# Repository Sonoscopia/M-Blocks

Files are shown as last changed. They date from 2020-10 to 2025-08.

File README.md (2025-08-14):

# M-Blocks
Modular MIDI Controllers

## INFO
M-Blocks is a projected developed by Sonoscopia Associação Cultural (www.sonoscopia.pt). 
It consists of several MIDI controllers (M-Controllers) that can be patched to a receiving interface (M-Brain) in a modular fashion, that is, connecting an arbitrary number (32 max.) and type of controllers such as buttons, knobs, faders, encoders, etc. 
The M-Brain than receives data from all the controllers via and maps them to MIDI messages sent to the output, either through USB (future implementation) or MIDI DIN connections.
The communication between modules is made using I2C (Inter-Integrated Circuit) using the Arduino platform (www.arduino.cc).  

### Note to programmers
When programming an M-Brain for the first time do not forget to set the EEPROM memory using /utilities/EEPROM_Preset_Clear/

## CHANGELOG

### version 0.1.2 (phobosfeijoada)
Fully functional M-Brain prototype and M-Controllers.
Continuous controls (ex: knobs) can now output notes, [see commit](https://github.com/Sonoscopia/M-Blocks/commit/bef133f0ddcc1b52bf48fc73a7da5345fef3f352).
M-Toggle code was modified to (MToggleAsButton) acting as M-Button to work with Phobos.
There are still some bugs when programming M-Brain but it works as long as one follows the manual and pays attention to the LED's.

### version 0.1.1 (francesinha)
Fully functional M-Brain prototype and M-Controllers. Needs testing...

### version 0.1.0 (protobrain)
First working version for M-Brain protoype version (the version with LED's instead of a screen). 

### version 0.0.3 (gopro)
As the code for M-Brain is getting bigger I moved the code development to Atmel Studio. In the 'firmware' folder should be a version to compile in Arduino IDE for those of you who don't have Atmel Studio. 

### version 0.0.2 (whoisthemaster)
Inverted Master/Slave relationship. 
Now M-Brain is the slave and M-Controllers are masters.
This way the controllers send data whenever their hardware sensor data changes, while the slave (M-Brain) is requested to read this data. 

### version 0.0.1 (first prototype)
First working sketch containing two modules (MBrain and MToggle).
In this version the controller (MToggle) acts as a Slave device and MBrain acts as a Master device, where the slave is constantly sending data to the master with a flag to let the master know if data has changed or not. 

## CONTRIBUTORS 
Contributors: Gustavo Costa, Tiago Ângelo, Rui Dias, Ján Solčáni and PierrePierrePierre.

## DEPENDENCIES & ACKNOWLEDGEMENTS
- Wire library (https://www.arduino.cc/en/reference/wire) 
- EEPROM library (https://www.arduino.cc/en/Reference/EEPROM)
- Rotary library by Ben Buxton(https://github.com/brianlow/Rotary)
- MIDI Library by François Best (https://github.com/FortySevenEffects/arduino_midi_library)
- TimerOne Library (https://www.arduino.cc/reference/en/libraries/timerone/)

## LICENSE
[][cc-by-nc]

This work is licensed under a
[Creative Commons Attribution-NonCommercial 4.0 International License][cc-by-nc].

[][cc-by-nc]

[cc-by-nc]: https://creativecommons.org/licenses/by-nc/4.0/
[cc-by-nc-image]: https://licensebuttons.net/l/by-nc/4.0/88x31.png
[cc-by-nc-shield]: https://img.shields.io/badge/License-CC%20BY--NC%204.0-lightgrey.svg

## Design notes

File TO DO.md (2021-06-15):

# TO DO 

- change all M-Encoders debug baud rate to 9600 (it's just more common!...)

- hardware fix on M-Brain: protect TRRS sockets from delivering 12V to the I2C SCL and SDA connections when connecting cables after the unit is already powered (can this be done only in the M-Brain instead of adding circuitry to all M-Controllers ???)

- make code for: M-Encoders and M-Trackpad

- M-Brain: check resetMsg() - does it need to be called so often ??? 

- M-Brain: resetMsg() function name is misleading!! Change name

- M-Brain: line:272 - does setting the global channel needs to have an I2C message received ?!?!?!

- make M-Brain code a bit more efficient (leave original code commented to facilitate understanding)

- implement USB MIDI 

- buy/apply rubber feet to the cases

- buy/apply velcro dust protection on the M-Fader faders

# NOTES

- the M-Encoder board (eagle file) is a bit messy: clean it up!

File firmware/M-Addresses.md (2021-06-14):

#M-Controllers Address List: 

(Address from 0 to 31. Not to be confused with I2C address!)

0: M-Toggle1
1: M-Knob1
2: M-Button1
3: M-Fader1
4: M-Joystick1
5: M-Enc-C1 (control change)
6: M-Enc-C1 (notes)
7: M-Enc-D1 (control change) 
8: M-Enc-D1 (notes)

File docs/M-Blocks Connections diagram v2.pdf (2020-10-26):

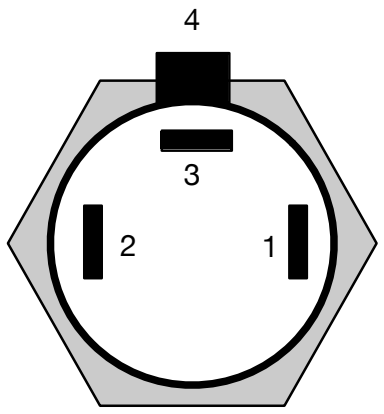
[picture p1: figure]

+12V
SCL
SDA
GND
1) +12V
2) SCL
3) SDA
4) GND

BROWN
RED
ORANGE

YELLOW SDA SCL

GND
+12V

## TRRS CONNECTIONS

(latest version 26-10-2020)

## MOLEX CONNECTIONS

SDA
SCL
GND
+12V
1) SDA
2) SCL
3) GND
4) +12V

BROWN
RED
ORANGE

YELLOW SDA SCL

GND
+12V

## TRRS CONNECTIONS

(older version)

## MOLEX CONNECTIONS

## WARNING

!

Having the +12V connected to the TRRS Sleeve prevents short-circuits when connecting modules while the M-BRAIN is already powered !!!

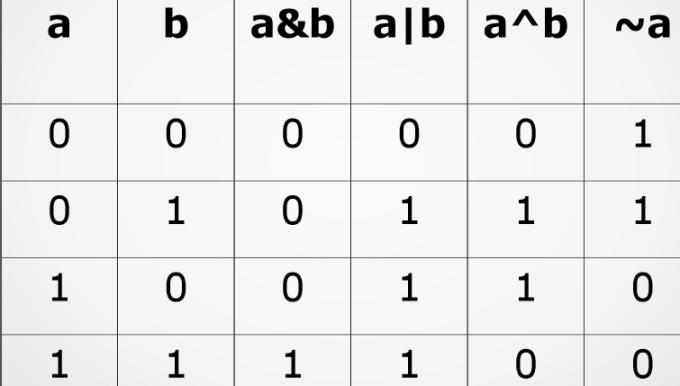
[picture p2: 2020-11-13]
docs/bitwise operator table.png

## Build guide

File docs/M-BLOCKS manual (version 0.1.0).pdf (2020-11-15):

# M-BLOCKS

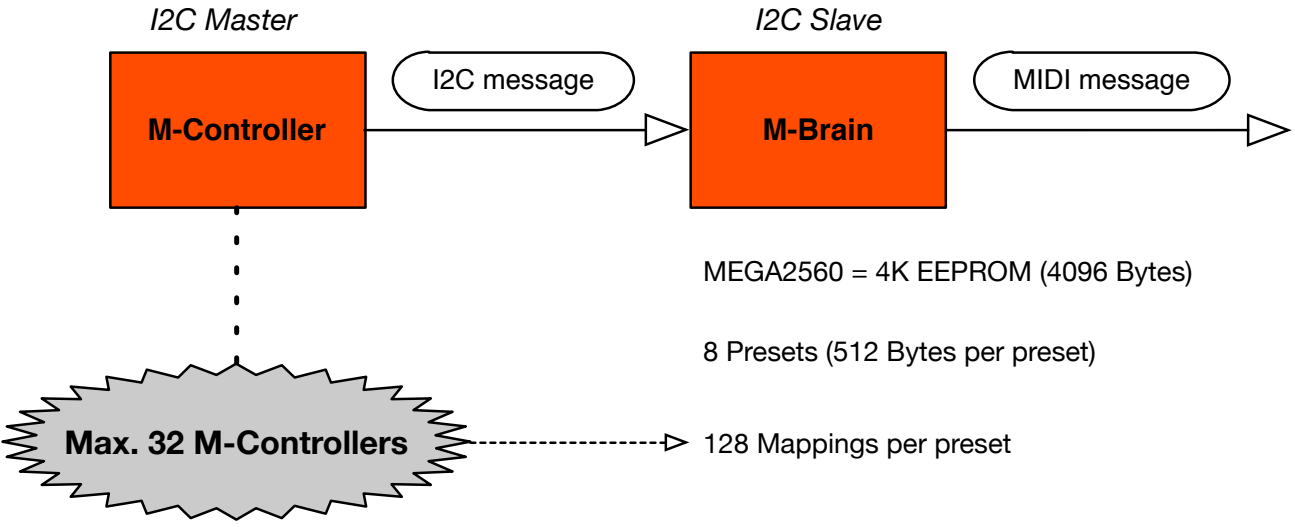
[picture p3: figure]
M-Controller; M-Brain; I2C Master; I2C Slave; I2C message; MIDI message; Max. 32 M-Controllers; MEGA2560 = 4K EEPROM (4096 Bytes); 8 Presets (512 Bytes per preset); 128 Mappings per preset

M-Encoders count as 2 M-Controllers. Encoder rotation as 1 controller and encoder button as another controller. By default encoder button press speeds up encoder rotation. Hold encoder button at startup to enable button output as separate message.

### NOTE:

## I2C Message

CTRL
ID

CTRL
Data

2 Bytes

7-bit (0 to 127)
ex: knob position

7-bit:

M-Controller ID (0 to 31)

Control ID (0 to 3)

unused
8th bit

0 0 0 0 0 0 0 0

Messages are sent upon control data change.

### Example

1 2

3 4

M-Knob

M-Controller ID = 4

M-Controller ID = 4

Control ID = 2

0 1 0 0 0 1 0 0

## EEPROM Memory

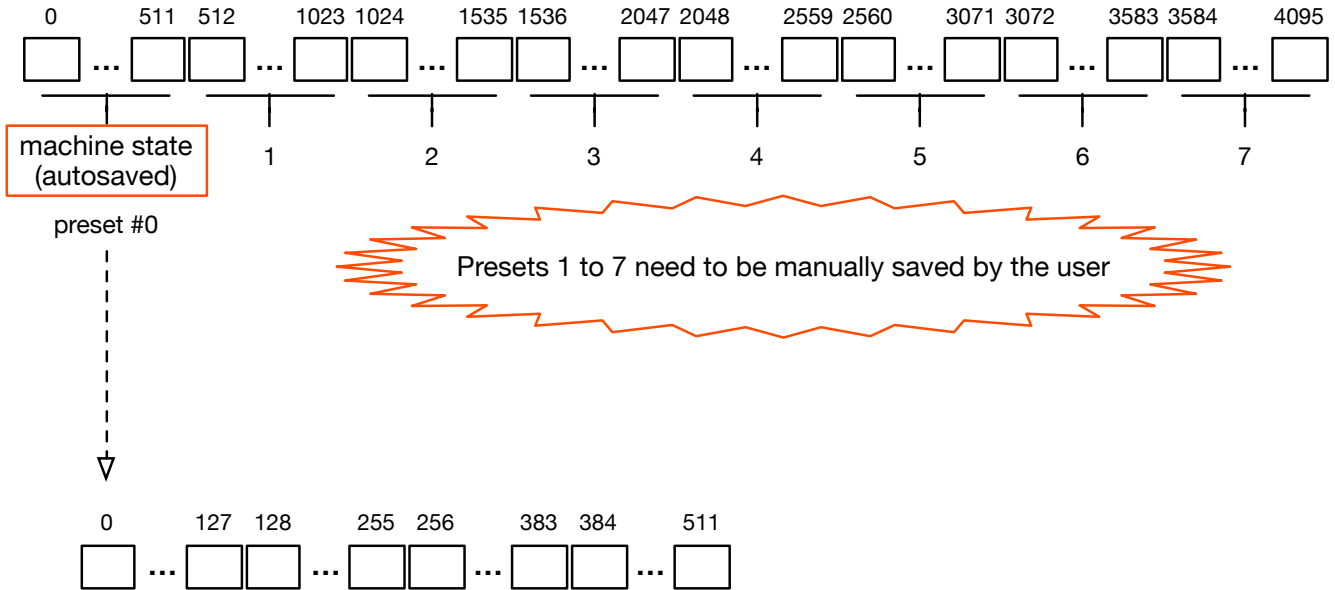
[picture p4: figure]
preset #0; machine state; (autosaved)

Presets 1 to 7 need to be manually saved by the user

CH | NOTE | VEL | CC
MIDI Channel | MIDI Note | Max. Velocity | CC number

NOTE: CTRL ID maps directly to EEPROM memory index

### Example

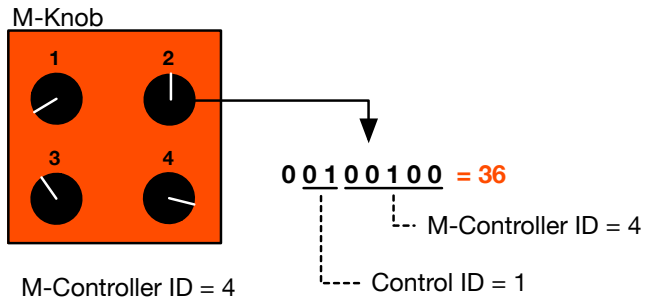
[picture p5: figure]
M-Knob; M-Controller ID = 4; Control ID = 1

CH = EEPROM [ 0 + 36 ]
NOTE = EEPROM [ 128 + 36 ] VEL = EEPROM [ 256 + 36 ]
CC = EEPROM [ 384 + 36 ]

# USER MANUAL

1) Set NOTE mapping
1.1) Press and hold [NOTE] + [Controller] => (LED - blink 250ms)
1.2) Press [LOAD] to EXIT => (LED - stop blinking)
1.3.1) Rotate [ENCODER] to set note number => (LED - display note number)
1.3.2) Press [ENTER] to confirm => (LED - stop blinking)

[NAME] = M-Brain button name
[Controller] = activate M-Controller hardware input (ex: knob, button, etc.) => (LED - xxxxxx) = represent 7-led activity
=> (LEDX - xxxxxx) = represent X-led activity
=> (LED13 - xxxx) = represent built_in led activity
2) Set MAXIMUM VELOCITY mapping
2.1) Press and hold [NOTE + CC] + [Controller] => (LED - blink 125ms)
2.2) Press [LOAD] to EXIT => (LED - stop blinking)
2.3.1) Rotate [ENCODER] to set maximum velocity => (LED - display velocity number)
2.3.2) Press [ENTER] to confirm => (LED - stop blinking)
3) Set CC mapping
3.1) Press and hold [CC] + [Controller] => (LED - blink 250ms)
3.2) Press [LOAD] to EXIT => (LED - stop blinking)
3.3.1) Rotate [ENCODER] to set CC number => (LED - display CC number)
3.3.2) Press [ENTER] to confirm => (LED - stop blinking)

6) SAVE preset
6.1) Press [SAVE] => (LED - blink 500ms)
6.2) Press [SAVE] again to EXIT => (LED - stop blinking)
6.3.1) Rotate [ENCODER] to set preset location => (LED - display slot number)
6.3.2) Press [ENTER] to save => (LED - blink twice)
7) LOAD preset
7.1) Press [LOAD] => (LED - blink 1000ms)
7.2) Press [LOAD] again to EXIT => (LED - stop blinking)
7.3.1) Rotate [ENCODER] to set preset location => (LED - display slot number)
7.3.2) Press [ENTER] to load => (LED - blink twice)
4) Set CH mapping (channel 0 = GLOBAL CH)
4.1) Press and hold [NOTE + LOAD] + [Controller] => (LED - blink 125ms)
4.2) Press [LOAD] to EXIT => (LED - stop blinking)
4.3.1) Rotate [ENCODER] to set CH number => (LED - display CC number)
4.3.2) Press [ENTER] to confirm => (LED - stop blinking)
5) Set GLOBAL CH
5.1) Press and hold [NOTE + CC + LOAD] + [Controller] => (LED - blink 250ms)
5.2) Press [LOAD] to EXIT => (LED - stop blinking)
5.3.1) Rotate [ENCODER] to set CH number => (LED - display CC number)
5.3.2) Press [ENTER] to confirm => (LED - stop blinking)
8) Clear preset 0 / init blank state
8.1) Disconnect M-Brain from power
8.2) Press and hold [LOAD+SAVE] while powering unit => (LED in reverse order)
9) Activate DEBUG Mode
9.1) Disconnect M-Brain from power
9.2) Press and hold [ENTER] while powering unit => (LED in reverse order)

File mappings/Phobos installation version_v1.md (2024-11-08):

# M-BLOCKS (Phobos installation version v1 - 08-11-2024) 

Versão em exibição permanente na Sonoscopia

### M-Joystick => mudar o código p/ enviar 4 CC's em vez de 2 [EnsembleOne hub-A]
* 1 - taça1 = 0
* 2 - taça2 = 1
* 3 - taça3 = 2
* 4 - taça4 = 3

### M-Toggle => mudar o código p/ funcionar como o M-Button mas c/ luz na mesma [EnsembleFour hub-C]
* 1 - USA wblock =39 
* 2 - USA barra =40 
* 3 - USA pratinho =41 
* 4 - USA taça =42 

### M-Button [EnsembleTwo hub-C]
* 1 - tarola1 =20 
* 2 - tarola2 =21 
* 3 - pandeiro1 =22 
* 4 - pandeiro2 =23 

### M-Knob [EnsembleEight hub-A and hub-B]
* 1 - tubo ralo =71 
* 2 - shaker =73 
* 3 - ventoinha berlinde =72 
* 4 - ventoinha esferovite =76 

### M-Fader [EnsembleTwo hub-B]
* 1 - 1mola =16 
* 2 - 2molas =17 
* 3 - estardalhaço =18 
* 4 - prancha =19 

### M-Enc-D (opcional, porque só há 5 cabos) [EnsembleFour hub-B]
* 1 - cão1 =35 
* 2 - cão2 =36 
* 3 - cão3 =37 
* 4 - cão4 =38 

### M-Enc-C (opcional, porque só há 5 cabos) [EnsembleTwo hub-A]
* 1 - cordas1 =12 
* 2 - cordas2 =13 
* 3 - cordas3 =14 
* 4 - cordas4 =15

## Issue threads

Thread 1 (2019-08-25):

Not able to map controller before receiving data from it

p1nh0, 2019-08-25:
Steps:
1) connect M-Brain
2) connect controller to M-Brain
3) press NOTEMAP or VEL
4) press any controller button

Happening: M-Brain doesn't init mapping mode
Expected:  M-Brain should enter mapping mode

p1nh0, 2019-08-25:
Should the controller send data at setup( ) ?
(review code first just to make sure)

p1nh0, 2019-08-25:
check
https://github.com/Sonoscopia/M-Blocks/commit/ac2cbda2b69ecb664b5a9932ffefd0157b9e5051

and see if this problem persists

p1nh0, 2019-08-25:
fixed in 9f8049a8c51113fc72129f4fa5ef13e77ab4f727

Closed 2019-08-25.

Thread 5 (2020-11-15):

M-Toggle unpredictable toggle behaviour

p1nh0, 2020-11-15:
Some toggles are not precise: sometimes clicking will turn the led on and off on a single turn.
Inspect if it is an hardware or software issue.

p1nh0, 2020-11-15:
Also this happened
notes: 2 0 1
notes: 2 0 1
notes: 2 0 1
notes: 2 127 1
notes: 2 127 1
notes: 2 127 1

when the LED actually was turning on/off normally

p1nh0, 2021-06-13:
solved this issue with software debounce (there isn't much space in the case to make an hardware debounce)
solved on commit: c176f15c46b7167ebb134fbceeb455fabf47c275

Closed 2021-06-13.

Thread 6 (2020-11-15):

M-Brain mapping controller to MIDI

p1nh0, 2020-11-15:
Either the LED display isn't showing the correct MIDI mapping or the mapping wasn't made properly.
This happened only sometimes...
Couldn't figure out the cause yet.

p1nh0, 2020-11-15:
pressing LOAD(aka CANCEL) after executing the mapping helped: the mapping assignment failed less often but still happened sometimes

p1nh0, 2020-11-15:
the issue is: the 1st a mapping is done it is successful, the 2nd is unsuccessful, the 3rd is succeful, 4th unsuccessful, etc....

p1nh0, 2021-06-13:
If we manually load preset#0 after startup the problem disappears

p1nh0, 2021-06-13:
solved on commit: 567a9a4a3cc15a6865776724fbee91201a0e92ea

Closed 2021-06-13.

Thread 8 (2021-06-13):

M-Joystick noisy potentiometers

p1nh0, 2021-06-13:
The potentiometers on the Sparkfun joystick don't seem as good as the Bourns potentiometers on M-Knob, giving some 'false' readings, or maybe this is caused by the springs in the joystick (?!?!).
An exponential smoothing algorithm was implemented to address this issue. The algorithm's weight (W) might have to be different from unit to unit....

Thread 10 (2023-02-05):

update manual

p1nh0, 2023-02-05:
- update to version 0.1.2
- include known issues
- add power up warning

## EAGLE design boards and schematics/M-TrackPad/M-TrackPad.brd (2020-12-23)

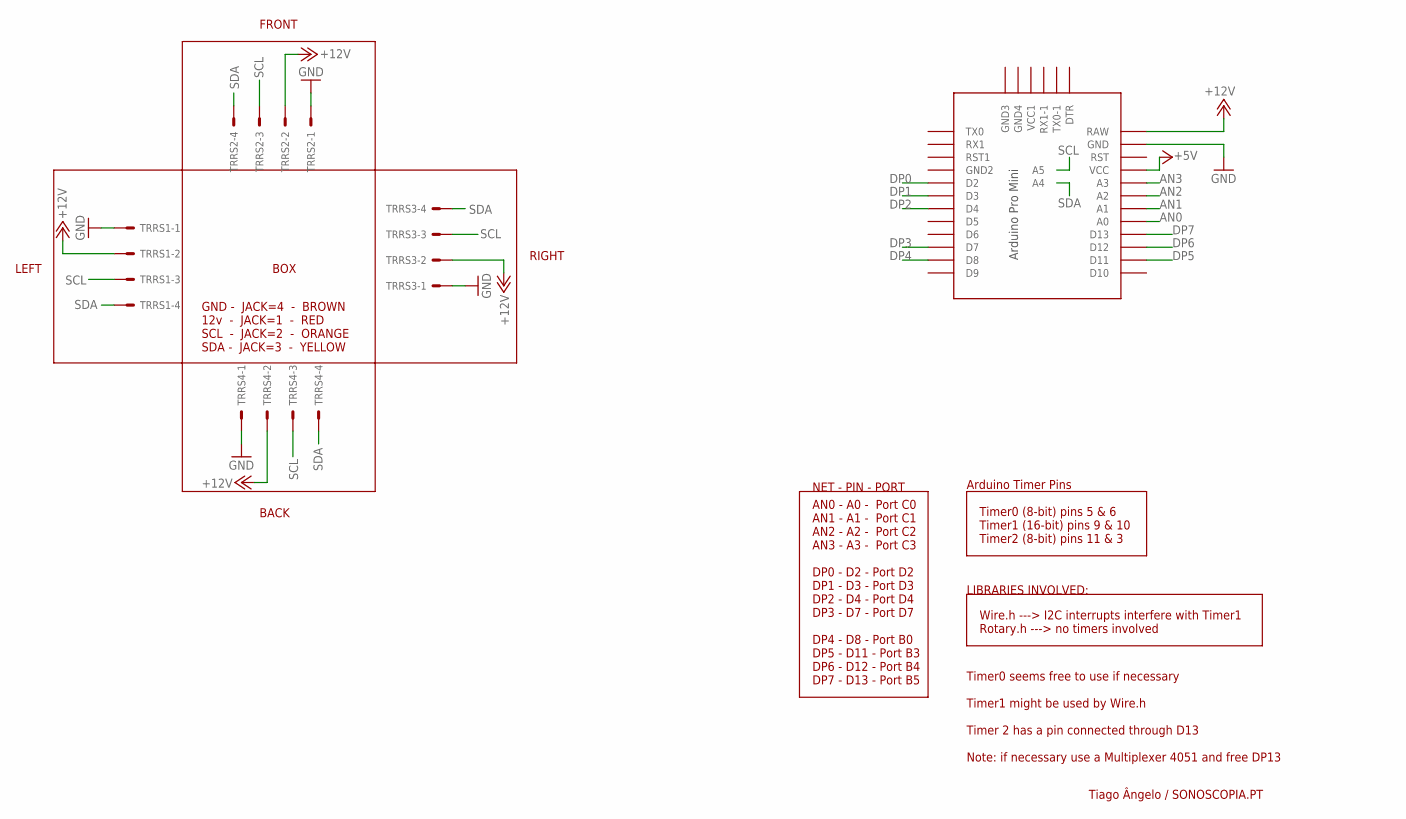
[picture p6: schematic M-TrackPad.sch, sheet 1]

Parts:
TRRS1, TRRS2, TRRS3, TRRS4: 22-27-2041-04; 6410-04
U$1: PRO-MINI-2

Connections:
+5V: U$1.VCC; also elsewhere on the board
+12V: TRRS1.2, TRRS2.2, TRRS3.2, TRRS4.2, U$1.RAW
AN0: U$1.A0
AN1: U$1.A1
AN2: U$1.A2
AN3: U$1.A3
DP0: U$1.D2; also elsewhere on the board
DP1: U$1.D3
DP2: U$1.D4
DP3: U$1.D7
DP4: U$1.D8
DP5: U$1.D11
DP6: U$1.D12
DP7: U$1.D13
GND: TRRS1.1, TRRS2.1, TRRS3.1, TRRS4.1, U$1.GND; also elsewhere on the board
SCL: TRRS1.3, TRRS2.3, TRRS3.3, TRRS4.3, U$1.A5; also elsewhere on the board
SDA: TRRS1.4, TRRS2.4, TRRS3.4, TRRS4.4, U$1.A4; also elsewhere on the board

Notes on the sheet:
Timer0 (8-bit) pins 5 & 6 Timer1 (16-bit) pins 9 & 10 Timer2 (8-bit) pins 11 & 3
Arduino Timer Pins
AN0 - A0 - Port C0 AN1 - A1 - Port C1 AN2 - A2 - Port C2 AN3 - A3 - Port C3 DP0 - D2 - Port D2 DP1 - D3 - Port D3 DP2 - D4 - Port D4 DP3 - D7 - Port D7 DP4 - D8 - Port B0 DP5 - D11 - Port B3 DP6 - D12 - Port B4 DP7 - D13 - Port B5
Wire.h ---> I2C interrupts interfere with Timer1 Rotary.h ---> no timers involved
LIBRARIES INVOLVED:
NET - PIN - PORT
Timer0 seems free to use if necessary Timer1 might be used by Wire.h Timer 2 has a pin connected through D13 Note: if necessary use a Multiplexer 4051 and free DP13
BOX
FRONT
RIGHT
LEFT
BACK
GND - JACK=4 - BROWN 12v - JACK=1 - RED SCL - JACK=2 - ORANGE SDA - JACK=3 - YELLOW
Tiago Ângelo / SONOSCOPIA.PT

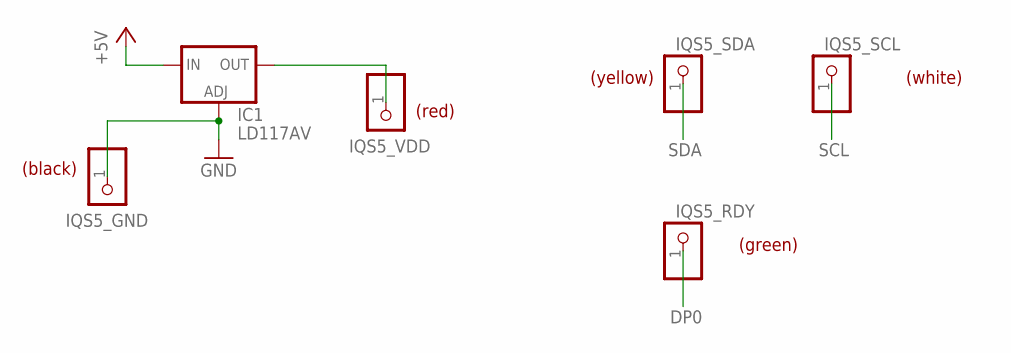
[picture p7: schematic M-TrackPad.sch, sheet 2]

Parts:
IC1: LD117AV; TO220L1
IQS5_GND, IQS5_RDY, IQS5_SCL, IQS5_SDA, IQS5_VDD: PINHD-1X1; 1X01

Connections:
+5V: IC1.3 (IN); also elsewhere on the board
DP0: IQS5_RDY.1; also elsewhere on the board
GND: IC1.1 (ADJ), IQS5_GND.1; also elsewhere on the board
unnamed: IC1.2 (OUT), IQS5_VDD.1
SCL: IQS5_SCL.1; also elsewhere on the board
SDA: IQS5_SDA.1; also elsewhere on the board

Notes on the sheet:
(black)
(red)
(yellow)
(white)
(green)

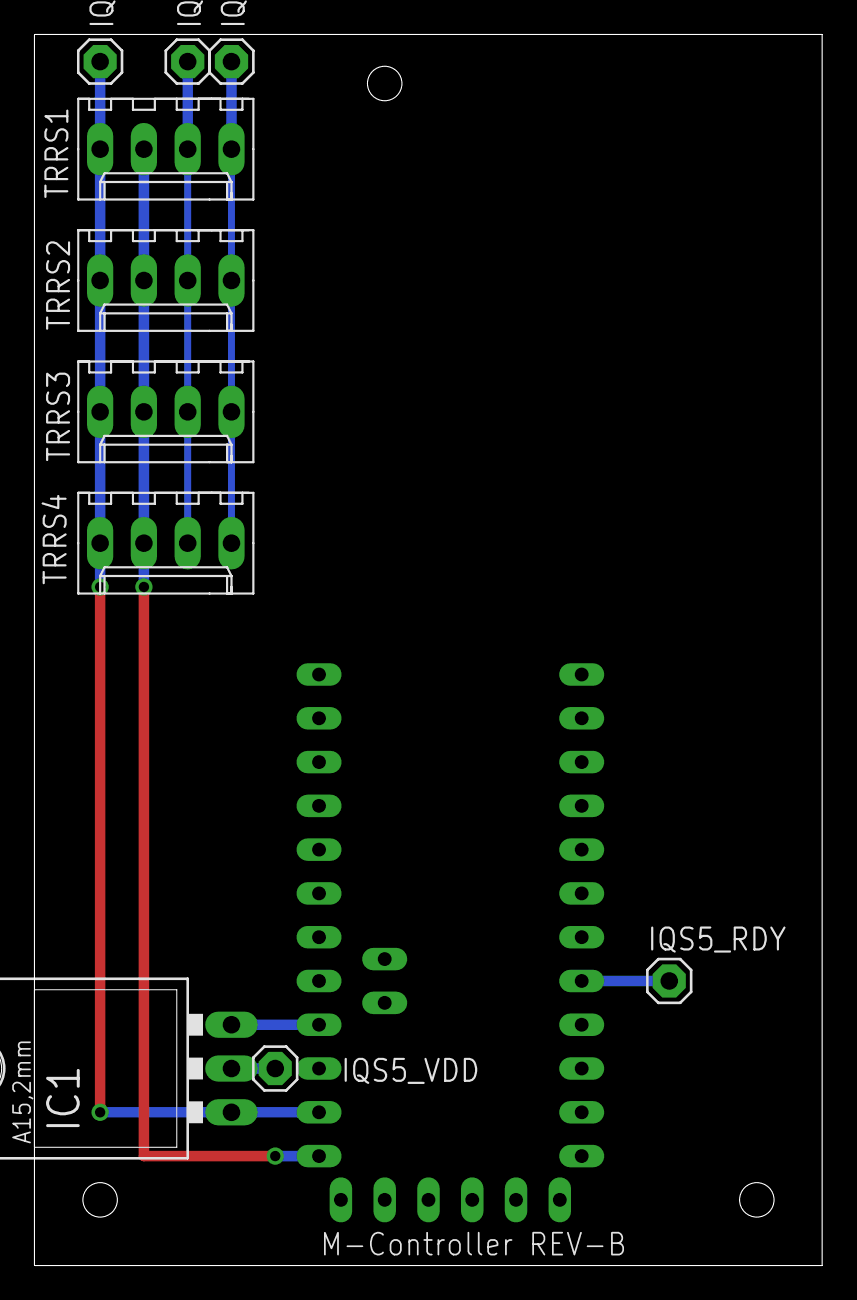
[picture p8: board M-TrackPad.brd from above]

Board: 2 copper layers, 45.7 x 71.4 mm, 11 parts (0 on the bottom side), 7 nets.

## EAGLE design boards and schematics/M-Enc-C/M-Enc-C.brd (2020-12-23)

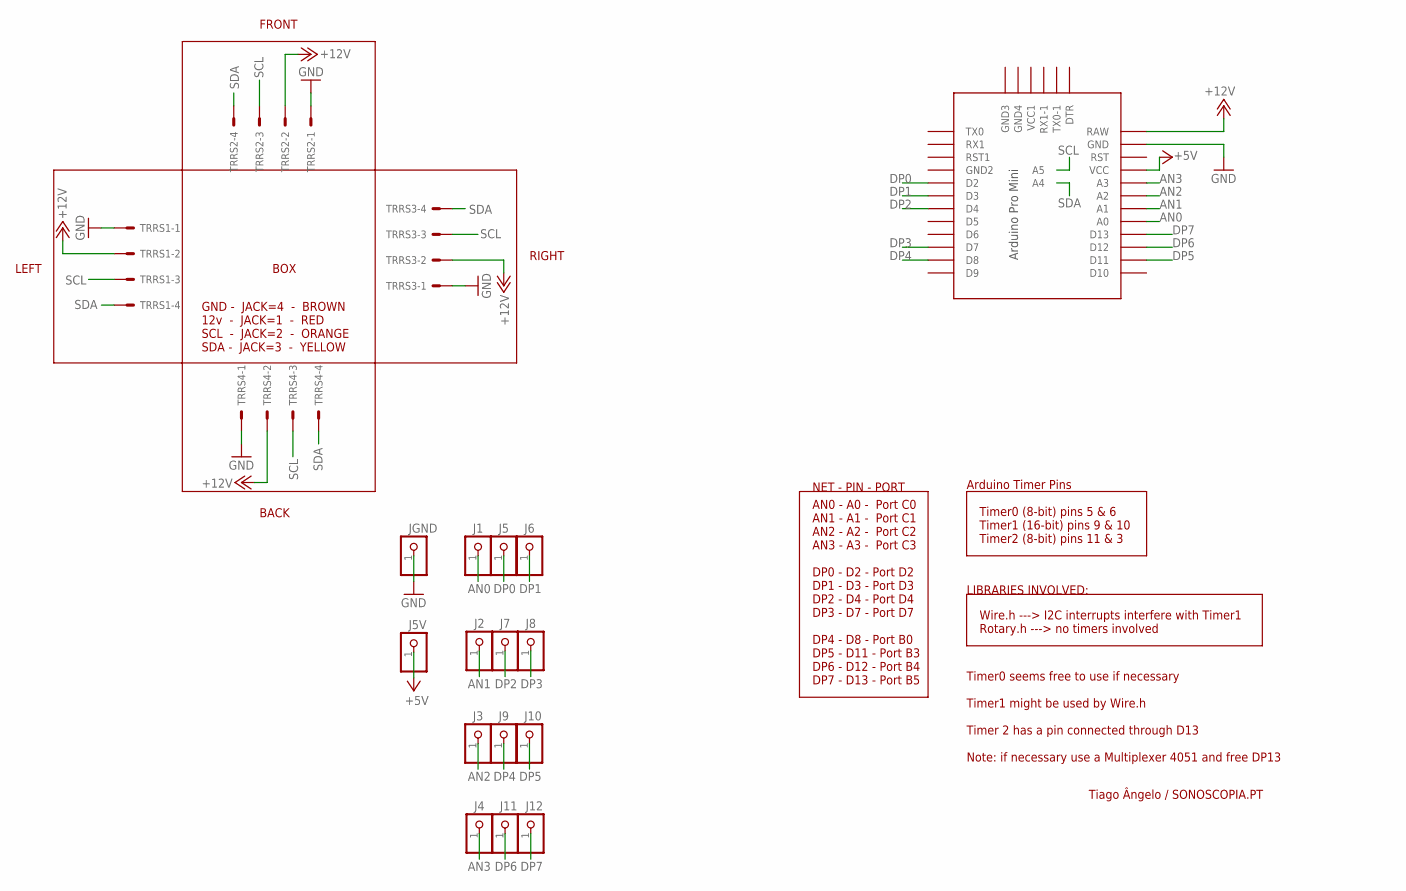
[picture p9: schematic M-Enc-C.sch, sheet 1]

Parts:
J1, J2, J3, J4, J5, J5V, J6, J7, J8, J9, J10, J11, J12: PINHD-1X1; 1X01
JGND: PINHD-1X1; 1X01
TRRS1, TRRS2, TRRS3, TRRS4: 22-27-2041-04; 6410-04
U$1: PRO-MINI-2

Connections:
+5V: J5V.1, U$1.VCC
+12V: TRRS1.2, TRRS2.2, TRRS3.2, TRRS4.2, U$1.RAW
AN0: J1.1, U$1.A0
AN1: J2.1, U$1.A1
AN2: J3.1, U$1.A2
AN3: J4.1, U$1.A3
DP0: J5.1, U$1.D2
DP1: J6.1, U$1.D3
DP2: J7.1, U$1.D4
DP3: J8.1, U$1.D7
DP4: J9.1, U$1.D8
DP5: J10.1, U$1.D11
DP6: J11.1, U$1.D12
DP7: J12.1, U$1.D13
GND: JGND.1, TRRS1.1, TRRS2.1, TRRS3.1, TRRS4.1, U$1.GND
SCL: TRRS1.3, TRRS2.3, TRRS3.3, TRRS4.3, U$1.A5
SDA: TRRS1.4, TRRS2.4, TRRS3.4, TRRS4.4, U$1.A4

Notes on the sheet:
Timer0 (8-bit) pins 5 & 6 Timer1 (16-bit) pins 9 & 10 Timer2 (8-bit) pins 11 & 3
Arduino Timer Pins
AN0 - A0 - Port C0 AN1 - A1 - Port C1 AN2 - A2 - Port C2 AN3 - A3 - Port C3 DP0 - D2 - Port D2 DP1 - D3 - Port D3 DP2 - D4 - Port D4 DP3 - D7 - Port D7 DP4 - D8 - Port B0 DP5 - D11 - Port B3 DP6 - D12 - Port B4 DP7 - D13 - Port B5
Wire.h ---> I2C interrupts interfere with Timer1 Rotary.h ---> no timers involved
LIBRARIES INVOLVED:
NET - PIN - PORT
Timer0 seems free to use if necessary Timer1 might be used by Wire.h Timer 2 has a pin connected through D13 Note: if necessary use a Multiplexer 4051 and free DP13
BOX
FRONT
RIGHT
LEFT
BACK
GND - JACK=4 - BROWN 12v - JACK=1 - RED SCL - JACK=2 - ORANGE SDA - JACK=3 - YELLOW
Tiago Ângelo / SONOSCOPIA.PT

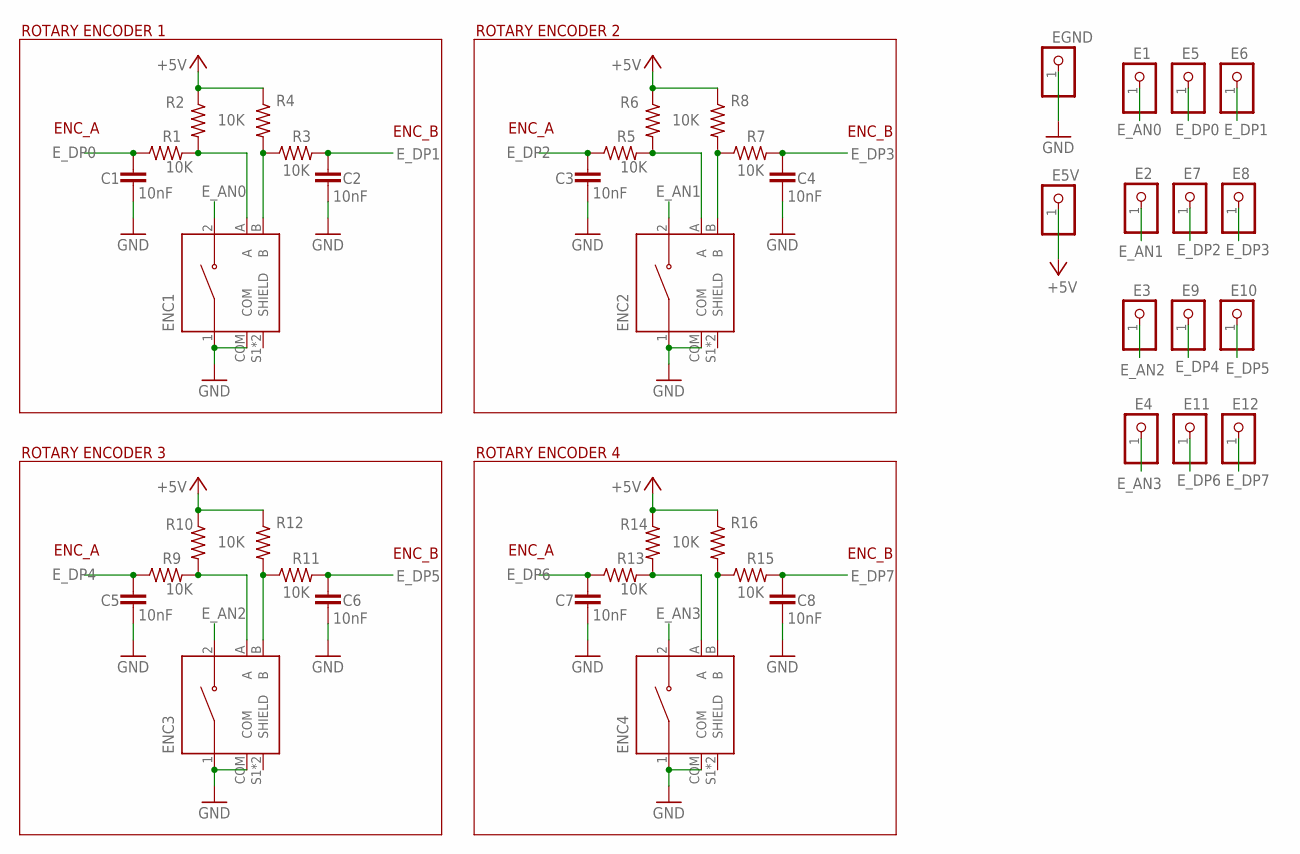
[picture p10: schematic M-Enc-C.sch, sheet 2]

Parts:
C1, C3: 10nF; C5B2.5
C2, C4, C5, C7: 10nF; C10B4
C6, C8: 10nF; C2.5-2
E1, E2, E3, E4, E5, E5V, E6, E7, E8, E9, E10, E11, E12: PINHD-1X1; 1X01
EGND: PINHD-1X1; 1X01
ENC1, ENC2, ENC3, ENC4: PEC11R-4215F-S0024; XDCR_PEC11R-4215F-S0024
R1, R2, R3, R5, R6, R7, R9, R11, R12, R13, R15, R16: 10K; 0204/7
R4, R8, R10, R14: 10K; 0207/12

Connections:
E_+5V: E5V.1, R2.1, R4.1, R6.1, R8.1, R10.1, R12.1, R14.1, R16.1
E_AN0: E1.1, ENC1.2
E_AN1: E2.1, ENC2.2
E_AN2: E3.1, ENC3.2
E_AN3: E4.1, ENC4.2
E_DP0: C1.1, E5.1, R1.1
E_DP1: C2.1, E6.1, R3.2
E_DP2: C3.1, E7.1, R5.1
E_DP3: C4.1, E8.1, R7.2
E_DP4: C5.1, E9.1, R9.1
E_DP5: C6.1, E10.1, R11.2
E_DP6: C7.1, E11.1, R13.1
E_DP7: C8.1, E12.1, R15.2
E_GND: C1.2, C2.2, C3.2, C4.2, C5.2, C6.2, C7.2, C8.2, EGND.1, ENC1.1, ENC1.COM, ENC2.1, ENC2.COM, ENC3.1, ENC3.COM, ENC4.1, ENC4.COM
unnamed: ENC2.A, R5.2, R6.2
unnamed: ENC1.B, R3.1, R4.2
unnamed: ENC2.B, R7.1, R8.2
unnamed: ENC3.A, R9.2, R10.2
unnamed: ENC3.B, R11.1, R12.2
unnamed: ENC4.A, R13.2, R14.2
unnamed: ENC4.B, R15.1, R16.2
unnamed: ENC1.A, R1.2, R2.2

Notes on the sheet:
ROTARY ENCODER 1
ENC_A
ENC_B
ROTARY ENCODER 2
ROTARY ENCODER 3
ROTARY ENCODER 4

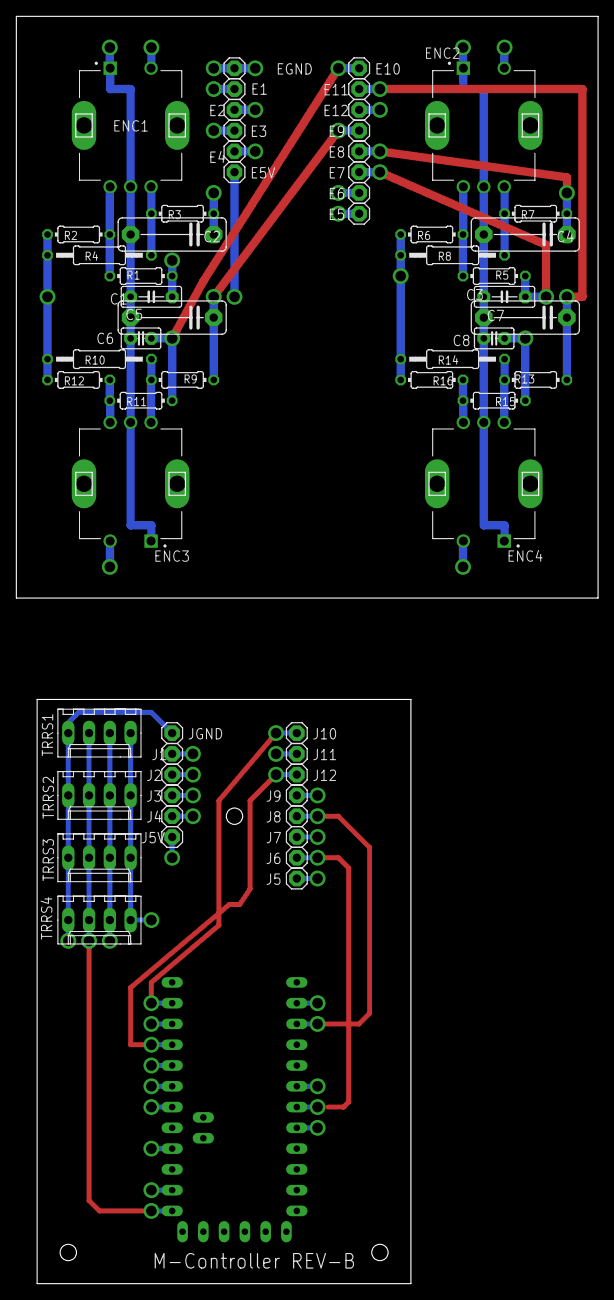
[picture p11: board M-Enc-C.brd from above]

Board: 7 copper layers, 71.1 x 154.9 mm, 61 parts (0 on the bottom side), 39 nets.

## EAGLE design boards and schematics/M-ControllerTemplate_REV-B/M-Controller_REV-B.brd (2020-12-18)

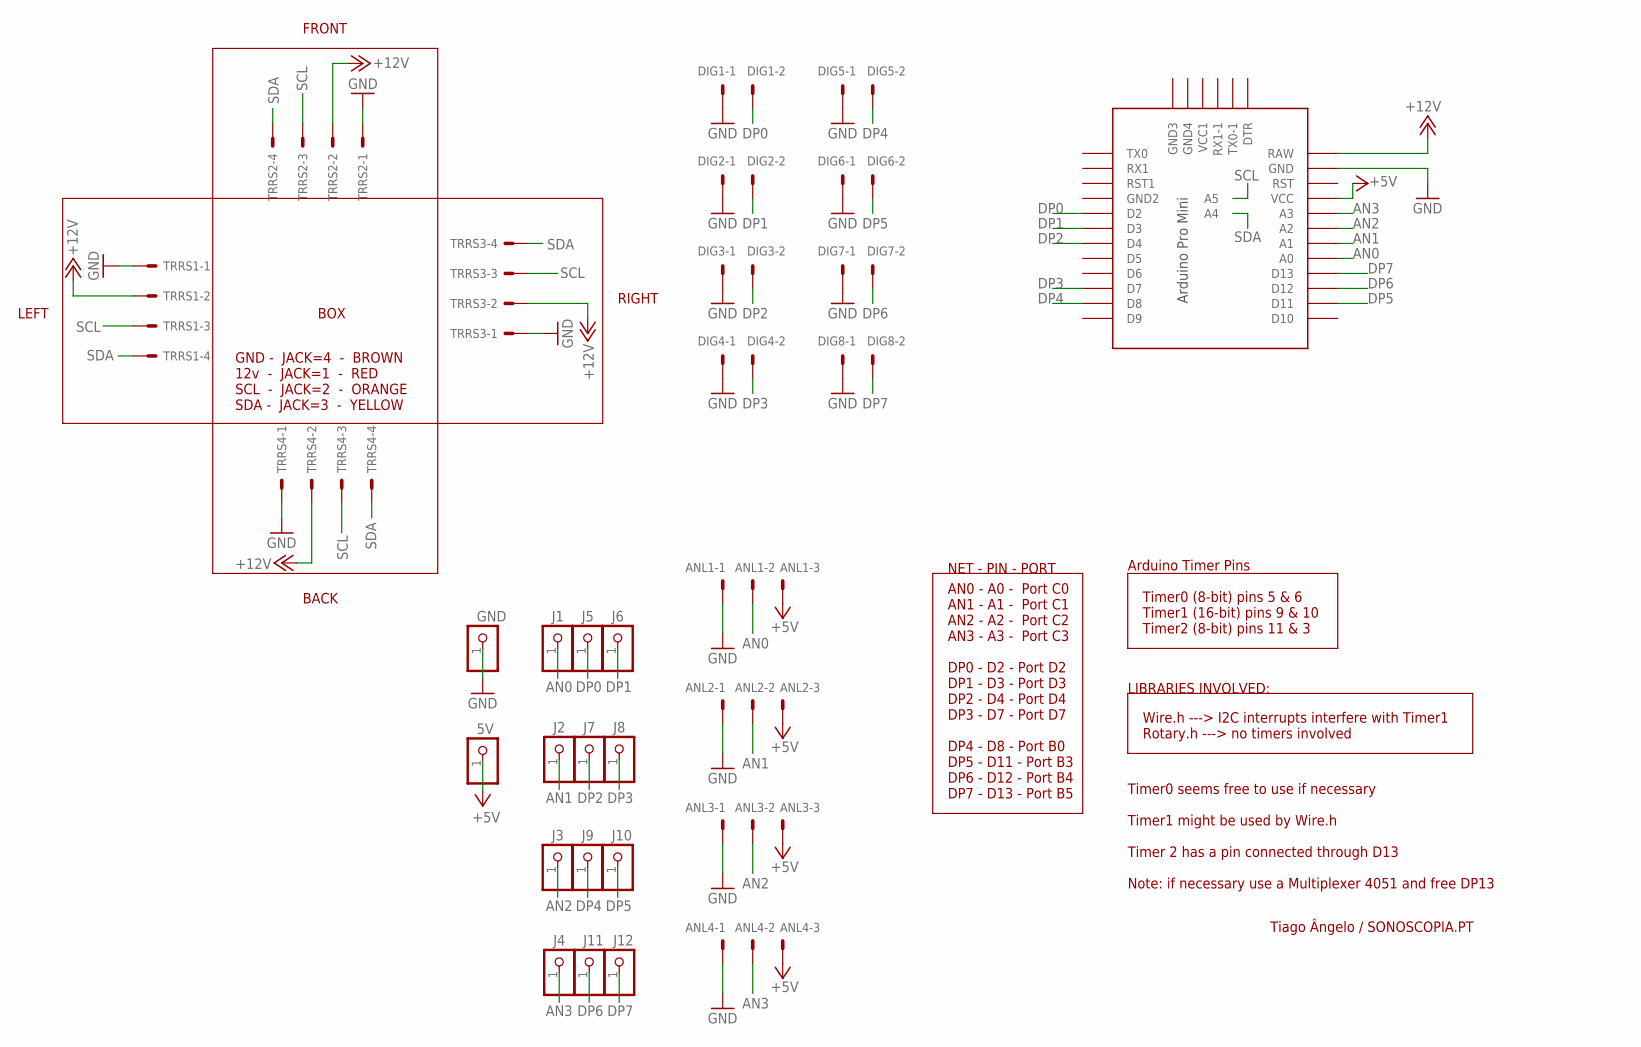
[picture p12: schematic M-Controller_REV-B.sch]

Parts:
5V: PINHD-1X1; 1X01
ANL1, ANL2, ANL3, ANL4: 22-27-2031-03; 6410-03
DIG1, DIG2, DIG3, DIG4, DIG5, DIG6, DIG7, DIG8: 22-27-2021-02; 6410-02
GND: PINHD-1X1; 1X01
J1, J2, J3, J4, J5, J6, J7, J8, J9, J10, J11, J12: PINHD-1X1; 1X01
TRRS1, TRRS2, TRRS3, TRRS4: 22-27-2041-04; 6410-04
U$1: PRO-MINI-2

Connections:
+5V: 5V.1, ANL1.3, ANL2.3, ANL3.3, ANL4.3, U$1.VCC
+12V: TRRS1.2, TRRS2.2, TRRS3.2, TRRS4.2, U$1.RAW
AN0: ANL1.2, J1.1, U$1.A0
AN1: ANL2.2, J2.1, U$1.A1
AN2: ANL3.2, J3.1, U$1.A2
AN3: ANL4.2, J4.1, U$1.A3
DP0: DIG1.2, J5.1, U$1.D2
DP1: DIG2.2, J6.1, U$1.D3
DP2: DIG3.2, J7.1, U$1.D4
DP3: DIG4.2, J8.1, U$1.D7
DP4: DIG5.2, J9.1, U$1.D8
DP5: DIG6.2, J10.1, U$1.D11
DP6: DIG7.2, J11.1, U$1.D12
DP7: DIG8.2, J12.1, U$1.D13
GND: ANL1.1, ANL2.1, ANL3.1, ANL4.1, DIG1.1, DIG2.1, DIG3.1, DIG4.1, DIG5.1, DIG6.1, DIG7.1, DIG8.1, GND.1, TRRS1.1, TRRS2.1, TRRS3.1, TRRS4.1, U$1.GND
SCL: TRRS1.3, TRRS2.3, TRRS3.3, TRRS4.3, U$1.A5
SDA: TRRS1.4, TRRS2.4, TRRS3.4, TRRS4.4, U$1.A4

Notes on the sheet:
Timer0 (8-bit) pins 5 & 6 Timer1 (16-bit) pins 9 & 10 Timer2 (8-bit) pins 11 & 3
Arduino Timer Pins
AN0 - A0 - Port C0 AN1 - A1 - Port C1 AN2 - A2 - Port C2 AN3 - A3 - Port C3 DP0 - D2 - Port D2 DP1 - D3 - Port D3 DP2 - D4 - Port D4 DP3 - D7 - Port D7 DP4 - D8 - Port B0 DP5 - D11 - Port B3 DP6 - D12 - Port B4 DP7 - D13 - Port B5
Wire.h ---> I2C interrupts interfere with Timer1 Rotary.h ---> no timers involved
LIBRARIES INVOLVED:
NET - PIN - PORT
Timer0 seems free to use if necessary Timer1 might be used by Wire.h Timer 2 has a pin connected through D13 Note: if necessary use a Multiplexer 4051 and free DP13
BOX
FRONT
RIGHT
LEFT
BACK
GND - JACK=4 - BROWN 12v - JACK=1 - RED SCL - JACK=2 - ORANGE SDA - JACK=3 - YELLOW
Tiago Ângelo / SONOSCOPIA.PT

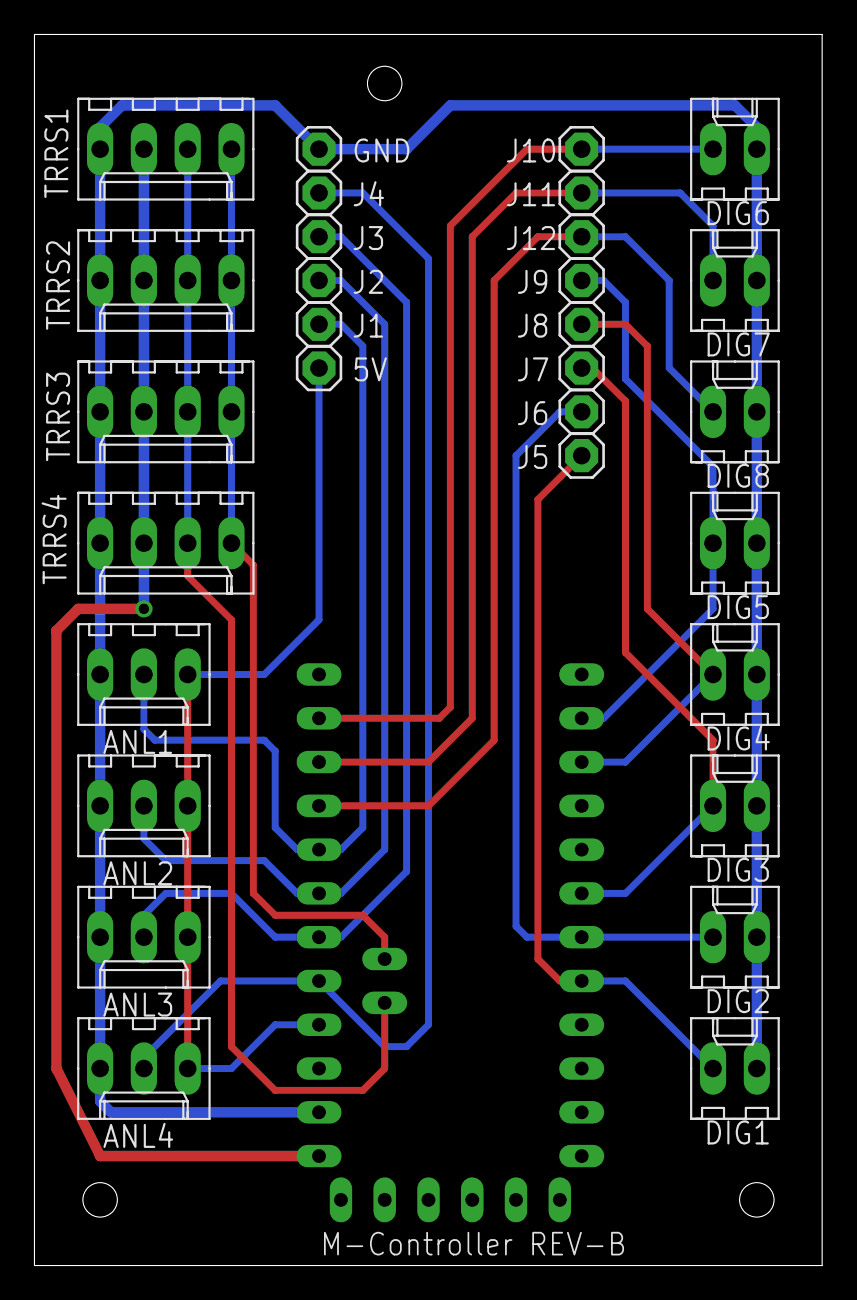
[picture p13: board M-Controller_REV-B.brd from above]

Board: 2 copper layers, 45.7 x 71.4 mm, 31 parts (0 on the bottom side), 17 nets.

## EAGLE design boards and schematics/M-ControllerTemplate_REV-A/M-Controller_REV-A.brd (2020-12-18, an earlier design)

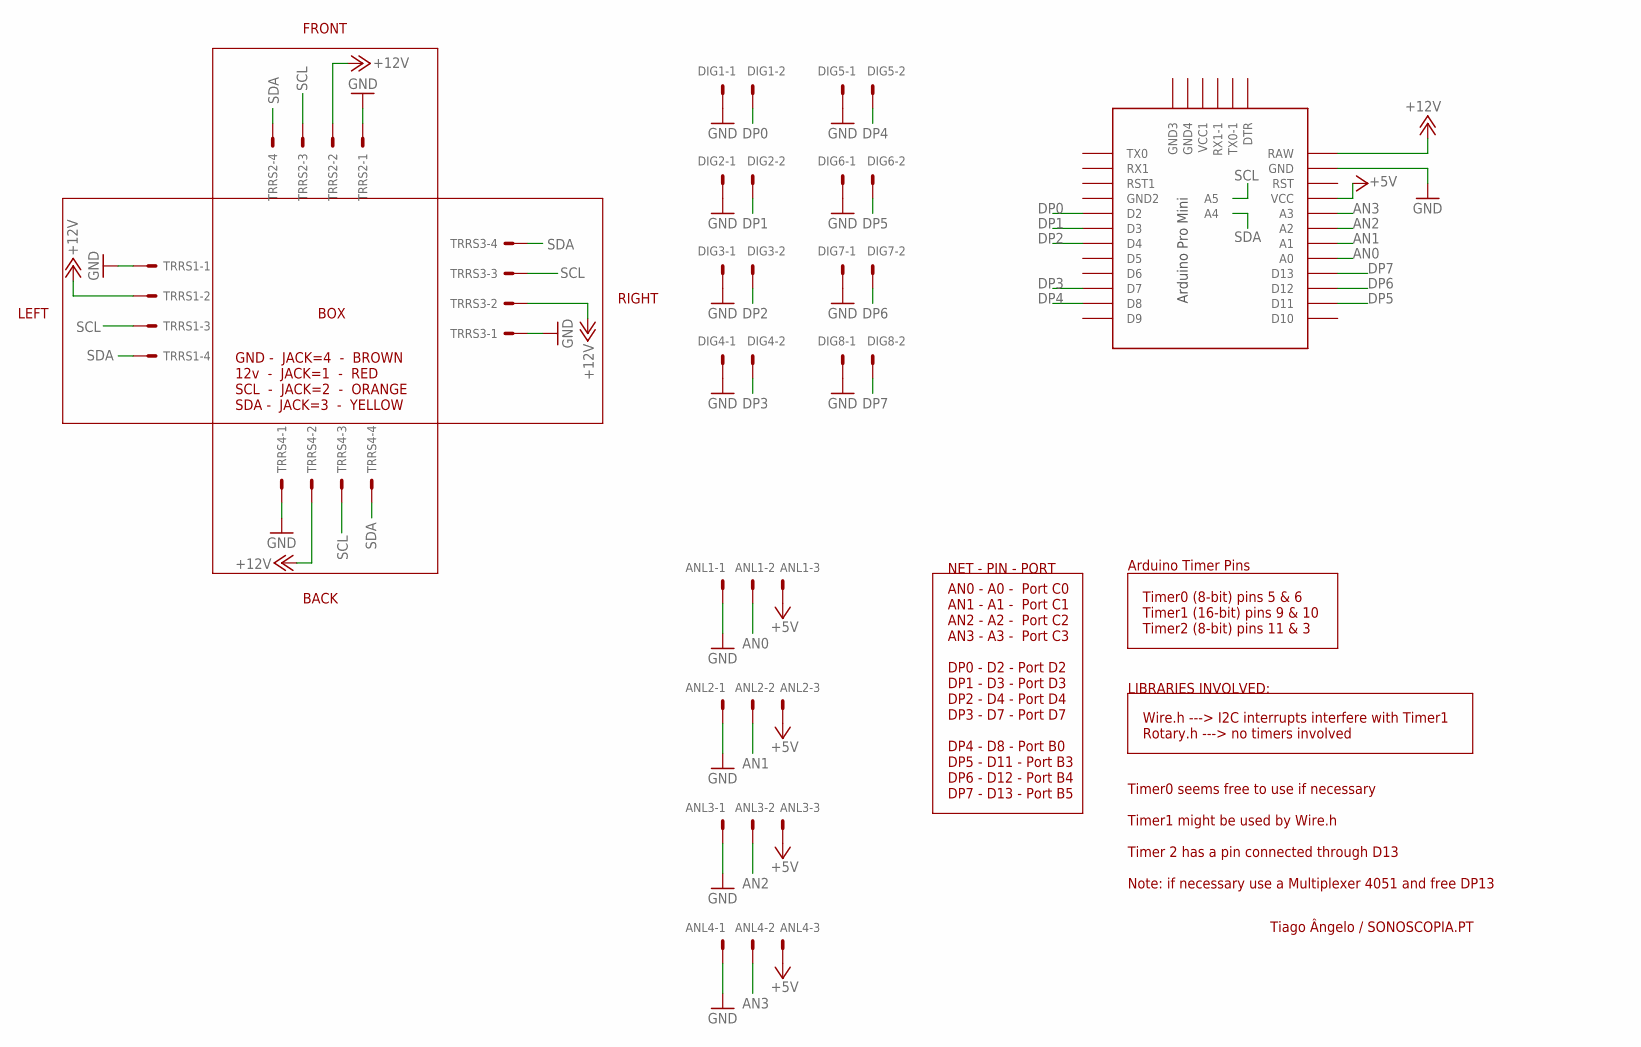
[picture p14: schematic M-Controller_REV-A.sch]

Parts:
ANL1, ANL2, ANL3, ANL4: 22-27-2031-03; 6410-03
DIG1, DIG2, DIG3, DIG4, DIG5, DIG6, DIG7, DIG8: 22-27-2021-02; 6410-02
TRRS1, TRRS2, TRRS3, TRRS4: 22-27-2041-04; 6410-04
U$1: PRO-MINI-2

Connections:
+5V: ANL1.3, ANL2.3, ANL3.3, ANL4.3, U$1.VCC
+12V: TRRS1.2, TRRS2.2, TRRS3.2, TRRS4.2, U$1.RAW
AN0: ANL1.2, U$1.A0
AN1: ANL2.2, U$1.A1
AN2: ANL3.2, U$1.A2
AN3: ANL4.2, U$1.A3
DP0: DIG1.2, U$1.D2
DP1: DIG2.2, U$1.D3
DP2: DIG3.2, U$1.D4
DP3: DIG4.2, U$1.D7
DP4: DIG5.2, U$1.D8
DP5: DIG6.2, U$1.D11
DP6: DIG7.2, U$1.D12
DP7: DIG8.2, U$1.D13
GND: ANL1.1, ANL2.1, ANL3.1, ANL4.1, DIG1.1, DIG2.1, DIG3.1, DIG4.1, DIG5.1, DIG6.1, DIG7.1, DIG8.1, TRRS1.1, TRRS2.1, TRRS3.1, TRRS4.1, U$1.GND
SCL: TRRS1.3, TRRS2.3, TRRS3.3, TRRS4.3, U$1.A5
SDA: TRRS1.4, TRRS2.4, TRRS3.4, TRRS4.4, U$1.A4

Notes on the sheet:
Timer0 (8-bit) pins 5 & 6 Timer1 (16-bit) pins 9 & 10 Timer2 (8-bit) pins 11 & 3
Arduino Timer Pins
AN0 - A0 - Port C0 AN1 - A1 - Port C1 AN2 - A2 - Port C2 AN3 - A3 - Port C3 DP0 - D2 - Port D2 DP1 - D3 - Port D3 DP2 - D4 - Port D4 DP3 - D7 - Port D7 DP4 - D8 - Port B0 DP5 - D11 - Port B3 DP6 - D12 - Port B4 DP7 - D13 - Port B5
Wire.h ---> I2C interrupts interfere with Timer1 Rotary.h ---> no timers involved
LIBRARIES INVOLVED:
NET - PIN - PORT
Timer0 seems free to use if necessary Timer1 might be used by Wire.h Timer 2 has a pin connected through D13 Note: if necessary use a Multiplexer 4051 and free DP13
BOX
FRONT
RIGHT
LEFT
BACK
GND - JACK=4 - BROWN 12v - JACK=1 - RED SCL - JACK=2 - ORANGE SDA - JACK=3 - YELLOW
Tiago Ângelo / SONOSCOPIA.PT

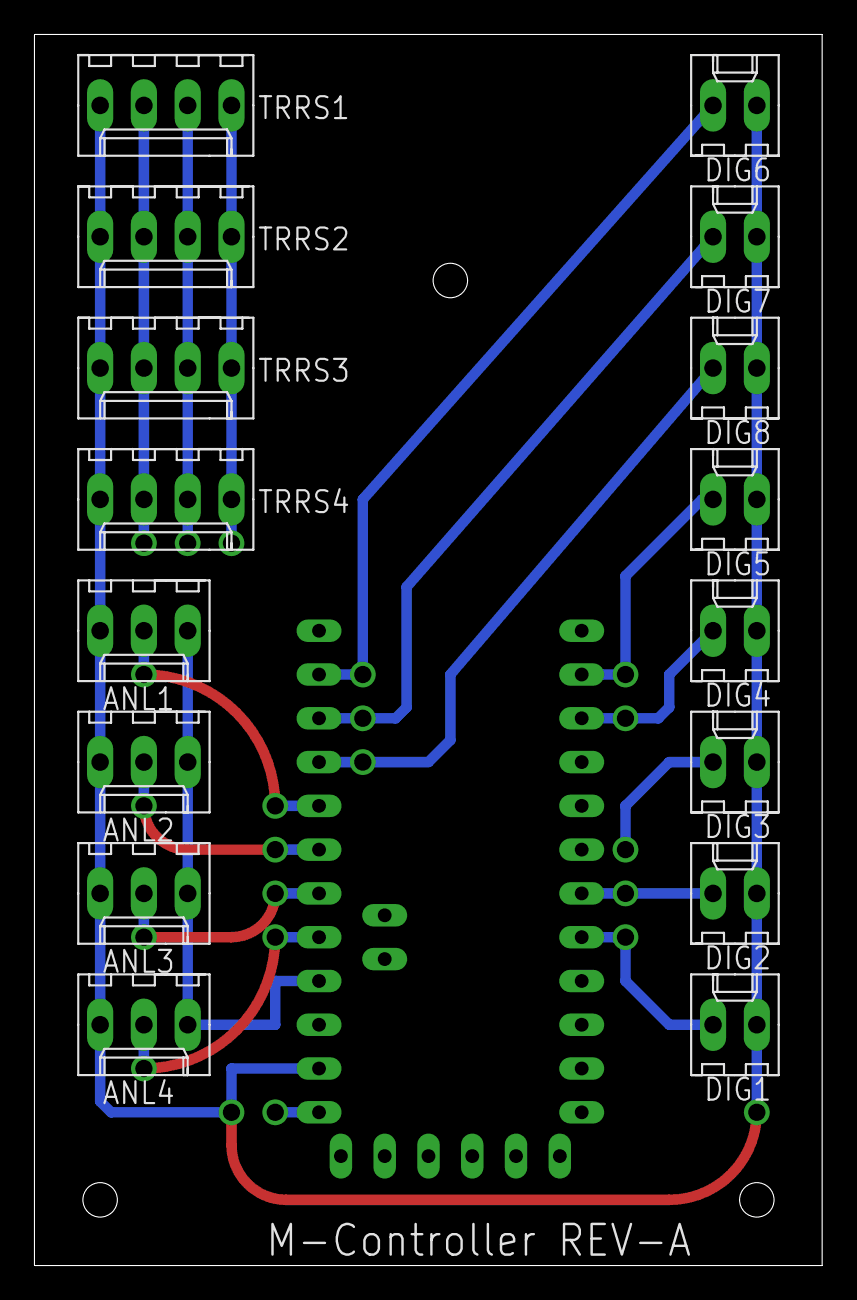
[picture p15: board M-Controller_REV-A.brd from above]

Board: 2 copper layers, 45.7 x 71.4 mm, 17 parts (0 on the bottom side), 17 nets.

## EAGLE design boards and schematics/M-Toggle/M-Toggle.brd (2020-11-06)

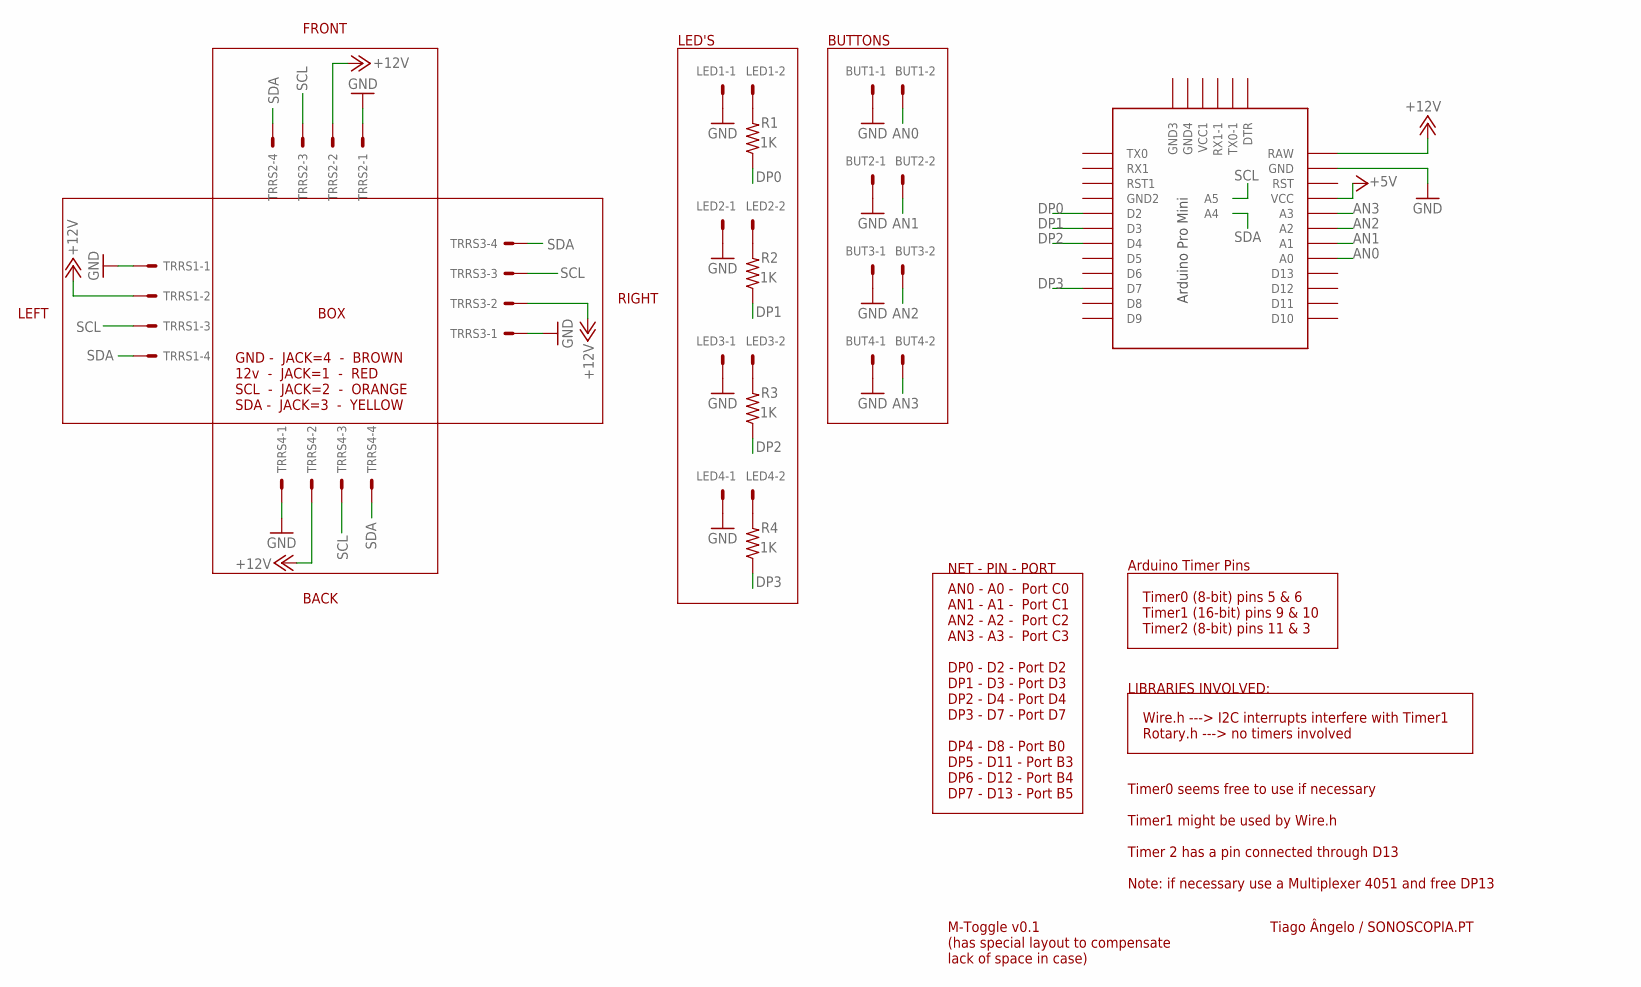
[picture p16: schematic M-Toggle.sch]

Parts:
BUT1, BUT2, BUT3, BUT4: 22-27-2021-02; 6410-02
LED1, LED2, LED3, LED4: 22-27-2021-02; 6410-02
R1, R2, R3, R4: 1K; 0204/7
TRRS1, TRRS2, TRRS3, TRRS4: 22-27-2041-04; 6410-04
U$1: PRO-MINI-2

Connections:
+5V: U$1.VCC
+12V: TRRS1.2, TRRS2.2, TRRS3.2, TRRS4.2, U$1.RAW
AN0: BUT1.2, U$1.A0
AN1: BUT2.2, U$1.A1
AN2: BUT3.2, U$1.A2
AN3: BUT4.2, U$1.A3
DP0: R1.1, U$1.D2
DP1: R2.1, U$1.D3
DP2: R3.1, U$1.D4
DP3: R4.1, U$1.D7
GND: BUT1.1, BUT2.1, BUT3.1, BUT4.1, LED1.1, LED2.1, LED3.1, LED4.1, TRRS1.1, TRRS2.1, TRRS3.1, TRRS4.1, U$1.GND
unnamed: LED1.2, R1.2
unnamed: LED2.2, R2.2
unnamed: LED3.2, R3.2
unnamed: LED4.2, R4.2
SCL: TRRS1.3, TRRS2.3, TRRS3.3, TRRS4.3, U$1.A5
SDA: TRRS1.4, TRRS2.4, TRRS3.4, TRRS4.4, U$1.A4

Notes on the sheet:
Timer0 (8-bit) pins 5 & 6 Timer1 (16-bit) pins 9 & 10 Timer2 (8-bit) pins 11 & 3
Arduino Timer Pins
AN0 - A0 - Port C0 AN1 - A1 - Port C1 AN2 - A2 - Port C2 AN3 - A3 - Port C3 DP0 - D2 - Port D2 DP1 - D3 - Port D3 DP2 - D4 - Port D4 DP3 - D7 - Port D7 DP4 - D8 - Port B0 DP5 - D11 - Port B3 DP6 - D12 - Port B4 DP7 - D13 - Port B5
Wire.h ---> I2C interrupts interfere with Timer1 Rotary.h ---> no timers involved
LIBRARIES INVOLVED:
NET - PIN - PORT
Timer0 seems free to use if necessary Timer1 might be used by Wire.h Timer 2 has a pin connected through D13 Note: if necessary use a Multiplexer 4051 and free DP13
BOX
FRONT
RIGHT
LEFT
BACK
GND - JACK=4 - BROWN 12v - JACK=1 - RED SCL - JACK=2 - ORANGE SDA - JACK=3 - YELLOW
LED'S
BUTTONS
M-Toggle v0.1 (has special layout to compensate lack of space in case)
Tiago Ângelo / SONOSCOPIA.PT

Board: 2 copper layers, 17 parts (0 on the bottom side), 16 nets, no tracks yet.

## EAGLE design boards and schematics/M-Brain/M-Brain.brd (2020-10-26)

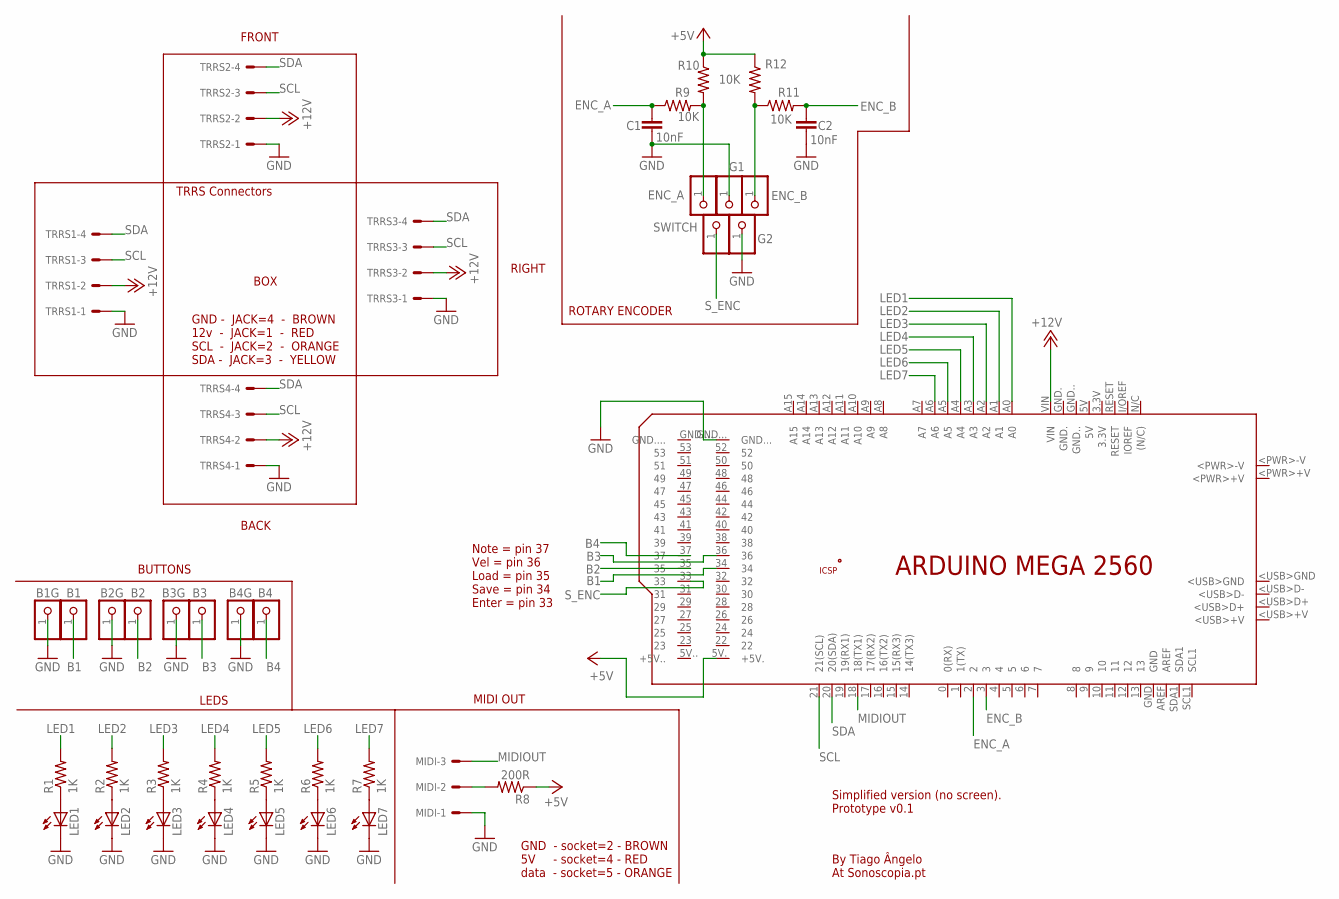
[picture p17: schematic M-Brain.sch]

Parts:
B1, B1G, B2, B2G, B3, B3G, B4, B4G: PINHD-1X1; 1X01
C1, C2: 10nF; C2.5-2
ENC_A: PINHD-1X1; 1X01
ENC_B: PINHD-1X1; 1X01
G1, G2: PINHD-1X1; 1X01
LED1, LED2, LED3, LED4, LED5, LED6, LED7: LED5MM
MIDI: 22-27-2031-03; 6410-03
PCB1: ARDUINO_MEGA2560
R1, R2, R3, R4, R5, R6, R7: 1K; 0204/5
R8: 200R; 0204/7
R9, R10, R11, R12: 10K; 0204/7
SWITCH: PINHD-1X1; 1X01
TRRS1, TRRS2, TRRS3, TRRS4: 22-27-2041-04; 6410-04

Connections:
+5V: PCB1.5V. (+5V.), R8.1, R10.1, R12.1
+12V: PCB1.VIN, TRRS1.2, TRRS2.2, TRRS3.2, TRRS4.2
B1: B1.1, PCB1.34
B2: B2.1, PCB1.35
B3: B3.1, PCB1.36
B4: B4.1, PCB1.37
ENC_A: C1.1, PCB1.2, R9.1
ENC_B: C2.1, PCB1.3, R11.2
GND: B1G.1, B2G.1, B3G.1, B4G.1, C1.2, C2.2, G1.1, G2.1, LED1.K (C), LED2.K (C), LED3.K (C), LED4.K (C), LED5.K (C), LED6.K (C), LED7.K (C), MIDI.1, PCB1.GND..., TRRS1.1, TRRS2.1, TRRS3.1, TRRS4.1
LED1: PCB1.A0, R1.2
LED2: PCB1.A1, R2.2
LED3: PCB1.A2, R3.2
LED4: PCB1.A3, R4.2
LED5: PCB1.A4, R5.2
LED6: PCB1.A5, R6.2
LED7: PCB1.A6, R7.2
MIDIOUT: MIDI.3, PCB1.18 (18(TX1))
unnamed: LED1.A, R1.1
unnamed: LED2.A, R2.1
unnamed: LED3.A, R3.1
unnamed: LED4.A, R4.1
unnamed: LED5.A, R5.1
unnamed: LED6.A, R6.1
unnamed: LED7.A, R7.1
unnamed: MIDI.2, R8.2
unnamed: ENC_A.1, R9.2, R10.2
unnamed: ENC_B.1, R11.1, R12.2
SCL: PCB1.21 (21(SCL)), TRRS1.3, TRRS2.3, TRRS3.3, TRRS4.3
SDA: PCB1.20 (20(SDA)), TRRS1.4, TRRS2.4, TRRS3.4, TRRS4.4
S_ENC: PCB1.33, SWITCH.1

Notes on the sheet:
Simplified version (no screen). Prototype v0.1
By Tiago Ângelo At Sonoscopia.pt
BOX
FRONT
RIGHT
BACK
BUTTONS
LEDS
MIDI OUT
ROTARY ENCODER
TRRS Connectors
Note = pin 37 Vel = pin 36 Load = pin 35 Save = pin 34 Enter = pin 33
GND - JACK=4 - BROWN 12v - JACK=1 - RED SCL - JACK=2 - ORANGE SDA - JACK=3 - YELLOW
GND - socket=2 - BROWN 5V - socket=4 - RED data - socket=5 - ORANGE


Board: 2 copper layers, 40 parts (0 on the bottom side), 30 nets.

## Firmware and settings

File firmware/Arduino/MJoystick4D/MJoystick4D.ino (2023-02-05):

/* 
 *  M-Joystick (Master Sender) using Arduino Pro Mini
 *  version 0.1.0
 *  
 *  Created: 12-11-2020
 *  Author: Tiago Ângelo (aka p1nh0)
*/
 
#include <Wire.h>

#define NUMBYTES 2 // number of bytes using in communication from M-Controllers to M-Brain
#define BRAIN 8 // Slave Receiver address (M-Brain)
#define MADDR 4 // M-Controller address
#define MADDRSIZE 5 // addres size in bits (5-bits: 0 to 31)
#define DEBUG 0
#define W 0.5f //exponential smoothing weight - 0 = slow, very smoothed; 1 = fast, no smooth 
// implemented to filter some noise on the analogRead
// probably caused by crappy potentiometers on the joystick?! 
// => try replacing the potentiometers...


char inputs[2] = {A1, A0}; // BUTTON PINS (X, Y)
int X, Y; 
                  // {X+, X-, Y+, Y-}
float XY4D[4] =        {0,  0 , 0 , 0 }; // 'real-time' analog pots reading                   
float potstate[4]  = {0 , 0 , 0 , 0 }; // current smoothed value; using floats because of the exponential filter
float _potstate[4] = {0 , 0 , 0 , 0 }; // last smoothed value; using floats because of the exponential filter
boolean changed = false; // used to check if toggles have changed 
byte addr = MADDR;
byte message[2] = {addr, potstate[0]};

void setup() {
  Wire.begin();// join i2c bus (address optional for master)
  if(DEBUG) Serial.begin(9600);
  pinMode(LED_BUILTIN, OUTPUT); // use built-in led to check for ADC flickers
  digitalWrite(LED_BUILTIN, LOW); 
  
  // update values upon startup
  X = setX(analogRead(inputs[0]));
  Y = setY(analogRead(inputs[1])); 
  XYto4D(X, Y, XY4D);
  XYto4D(X, Y, potstate); 
  _potstateUpdate();
}

void loop() {
  X = setX(analogRead(inputs[0]));
  Y = setY(analogRead(inputs[1])); 
  XYto4D(X, Y, XY4D);
  
  for (int i = 0; i < 4; i++){
    potstate[i] = expFilter(XY4D[i], _potstate[i], W);
    potstate[i] = round(potstate[i]);
    
    if( potstate[i] != _potstate[i] ){
      digitalWrite(LED_BUILTIN, HIGH); 
       // prepare message to send through I2C
      message[0] = MADDR + (i << MADDRSIZE);
      message[1] = (byte)(round(potstate[i])); // 0..127
      // send I2C message      
      Wire.beginTransmission(BRAIN);
      Wire.write(message, NUMBYTES);
      Wire.endTransmission();
      
      // DEBUG I2C MESSAGES
      if(DEBUG){
        changed = true; 
        Serial.print("I2C message to M-Brain on addr=");
        Serial.print(BRAIN);
        Serial.println(" :");
        Serial.print("ctrl_addres: ");
        Serial.print(message[0], BIN);
        Serial.print(" | ctrl_value: ");
        Serial.println(message[1]); 
      }
    }
    _potstate[i] = potstate[i];
  }
  
  // DEBUG HARDWARE CONTROLLERS
  if(changed && DEBUG ){
    for(int i=0; i < 4; i++){
      Serial.print(potstate[i]);
      Serial.print(" ");
    }
    Serial.println();
    changed = false;
  }
  
  digitalWrite(LED_BUILTIN, LOW);
}

// exponential smoothing formula: Yn = (w * Xn) + ((1-w) * Yn-1); 0 >= w <= 1; Xn = new value; Yn-1 = last smoothed value; 
float expFilter(float Xn, float Yn1, float w){
  return (w * Xn) + ((1.f-w) * Yn1); 
}

// set pot X value (-127 to 128)
int setX(int ar){
  int _x = 128 - (ar>>2);
  return _x; 
}
// set pot Y value (-127 to 128)
int setY(int ar){
  int _y = -127 + (ar>>2);
  return _y;
}

// convert X and Y to 4dimensions (X+, X-, Y+, Y-)
void XYto4D(int x, int y, float *d){
  if(x > 0){
      d[0] = x - 1;
      d[1] = 0; 
  }
  else {
    d[0]= 0;
    d[1] = abs(x);
  }

  if(Y > 0){
      d[2] = y - 1;
      d[3] = 0; 
  }
  else {
    d[2] = 0;
    d[3] = abs(y);
  }
}

void _potstateUpdate(){
  for(int i = 0; i < 4; i++){
    _potstate[i] = potstate[i];
  }
}

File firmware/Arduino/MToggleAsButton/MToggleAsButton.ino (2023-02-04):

/* 
 *  M-Toggle (Master Sender) using Arduino Pro Mini
 *  version 0.1.0
 *  
 *  this is a special code made specifically to control PHOBOS
 *  it basically acts like M-Button but it still lights up the LEDS, so...no toggle functionality
 *  
 *  Created: 12-11-2020
 *  Author: Tiago Ângelo (aka p1nh0)
*/

#include <Wire.h>

#define MADDR 0 // M-Controller address
#define MADDRSIZE 5 // addres size in bits (5-bits: 0 to 31)
#define BRAIN 8 // Slave Receiver address (M-Brain)
#define NUMBYTES 2 // number of bytes using in communication from M-Controllers to M-Brain
#define DEBUG 0

char inputs[4] = {A0, A1, A2, A3}; // BUTTON PINS 
byte leds[4] = {2, 3, 4, 7}; // LED PINS 
byte buttons[4] = {0, 0, 0, 0};
byte _buttons[4] = {0, 0, 0, 0};
long lastDebounceTime[4] = {0, 0, 0, 0};  // the last time the output pin was toggled
long debounceDelay = 10;    // the debounce time; increase if the output flickers
boolean changed = false; // used to check if toggles have changed 
byte addr = MADDR;
byte message[2] = {addr, buttons[0]};

void setup() {
  Wire.begin();// join i2c bus (address optional for master)
  if(DEBUG) Serial.begin(115200);
  
  // hardware setup
  for(int i = 0; i < 4; i++){
    pinMode(inputs[i], INPUT_PULLUP);
    pinMode(leds[i], OUTPUT); // led setup 
    digitalWrite(leds[i], LOW); // turn all leds off
  }
}

void loop() {
  for (int i = 0; i < 4; i++){
    buttons[i] = 1 - (analogRead(inputs[i])>>9); //read current button state
    if (buttons[i]) digitalWrite(leds[i], HIGH);
    else digitalWrite(leds[i], LOW);
    
    if(buttons[i] != _buttons[i]){
      lastDebounceTime[i] = millis();    
    }

    if((millis() - lastDebounceTime[i]) > debounceDelay){
      _buttons[i] = buttons[i];
    }

    if(buttons[i] != _buttons[i]){
      _buttons[i] = buttons[i];
      // prepare message to send through I2C
      message[0] = MADDR + (i << MADDRSIZE);
      message[1] = buttons[i] * 127;
      // send I2C message      
      Wire.beginTransmission(BRAIN);
      Wire.write(message, NUMBYTES);
      Wire.endTransmission();
      
      // DEBUG I2C MESSAGES
      if(DEBUG){
        changed = true; 
        Serial.print("I2C message to M-Brain on addr=");
        Serial.print(BRAIN);
        Serial.println(" :");
        Serial.print("ctrl_addres: ");
        Serial.print(message[0], BIN);
        Serial.print(" | ctrl_value: ");
        Serial.println(message[1]); 
      }   
    }
  }
  // DEBUG HARDWARE CONTROLLERS
  if(changed && DEBUG ){
    for(int i=0; i < 4; i++){
      Serial.print(buttons[i]);
      Serial.print(" ");
    }
    Serial.println();
    changed = false;
  }
}

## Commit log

2019-08-08 controller schematic first sketch
    [M-Controller.sch]
2019-08-08 minor schematic update
    [M-Controller.sch]
2019-08-08 replaced 5v input to 12V input onto the RAW pin
    12V is more consistent than 5V to "spread" between several modules
    [M-Controller.sch]
2019-08-08 minor change
    [M-Controller.sch]
2019-08-14 added example for super fast encoder reading
2019-08-14 updated schematic
    - noted timer and library issues
    - added all 4 TRRS connectors
    - mapped all I/O
    [M-Controller.sch]
2019-08-22 minor changes
    [M-Controller.brd, M-Controller.sch]
2019-08-22 changed board sized and fixed drill holes
    [M-Controller.brd]
2019-08-22 uploaded M-Toggle
    Veroboard version
    Revision 1
    [M-Toggle.brd, M-Toggle.sch]
2019-08-22 changed spacing in digital connectors
    the molex connectors would not fit
    [M-Controller.brd]
2019-08-22 toggle board minor changes
    [M-Toggle.brd]
2019-08-24 version 0.0.2
    Inverted Master/Slave relationship.
    Now M-Brain is the slave and M-Controllers are masters.
    This way the controllers send data whenever their hardware sensor data
    changes, while the slave (M-Brain) is requested to read this data.
    [MToggle.ino]
2019-08-24 simple working version
    - reads M-Toggle switches and sends MIDI
    - implemented encoder reading and conversion to 7leds with binary
    representation
2019-08-24 moved sketches to firmware/Arduino
    this folder should contain working versions of the code in
    firmware/Atmel
2019-08-25 added I2C receiver test
2019-08-25 error in a comment
    [MToggle.ino]
2019-08-25 now able to save machine state
    although there are still some issues (see issues)
    [GLOBALS.h]
2019-08-25 notemap and velocity map properly implemented
    code could still be more efficient, but lets leave that for later...
2019-08-25 uploaded M-Button code
2019-08-25 super simple sketch to print potentiometer values
2020-07-15 added rotary encoder snippet
2020-07-15 significant changes to M-Brain
    Changed the TRRS jack connection diagram in order to avoid short circuits
    [M-Brain.brd, M-Brain.sch]
2020-07-15 organized schematics in a folder structure
    now every controller has its own folder
    [M-Brain.brd, M-Brain.sch, M-Toggle.brd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]
2020-08-24 Updated m-controller template
    changes:
    - there was an error in the arduino pro library part, so a library was
    made in order to edit this part
    - added molex connectors
    [M-Controller.brd, M-Controller.sch]
2020-10-26 uploaded case design files
2020-10-26 changed TRRS connections
    plus added Molex connectors like the ones I'm using in hardware
    [M-Brain.brd, M-Brain.sch]
2020-10-27 M-toggle new circuit version
    for the smaller v2 cases
    [M-Toggle.brd, M-Toggle.sch]
2020-11-06 corrected mistake
    +5V was connected to RST instead of VCC
    [M-Controller.brd, M-Controller.sch, M-Toggle.brd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]
2020-11-06 uploaded M-Knob
    [M-Knob.brd, M-Knob.sch]
2020-11-08 removed MController tester
    MController testers are redundant since the firmware allows to set a
    DEBUG variable which will print hardware state
2020-11-10 doc moving to v0.1.0
    moving from v.0.0.3 to v0.1.0
    almost there to functional prototype
2020-11-12 minor correction
    [M-Brain.sch]
2020-11-13 output value change
    change output to 127 if button is on
2020-11-13 implemented other map functions
    mapping functions implemented:
    - note (implemented in previous commit)
    - velocity
    - CC
    - CH
    - set global channel
2020-11-13 added tester
    test encoder rotation and led's on M-Brain boards
2020-11-13 ported Atmel version to Arduino IDE
2020-12-16 minor change
    changed vertical measure to inches because it's easier to count the
    holes in the veroboard to cut
    [M-Controller.brd]
2020-12-16 added M-Button schematic and board
    [M-Button.brd, M-Button.sch]
2020-12-17 added M-Fader schematic and board
    [M-Fader.brd, M-Fader.sch]
2020-12-18 M-Controller template Revision B
    changed board because of M-Encoder since the encoders have RC filters to
    improve readings and these components wouldn't fit on the board and
    would break compatibility between different M-Controller boards.
    M-Encoder has a 2nd board containing the RC filters.
    [M-Controller_REV-A.brd, M-Controller_REV-A.sch, M-Controller_REV-B.brd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]
2020-12-21 added Encoder-C board and schematic
    [M-Enc-C.brd, M-Enc-C.sch]
2020-12-23 Revert "minor changes"
    This reverts commit 44245df26b32f1cf179dd13bb4aecd7d2b900a5f.
    [M-Enc-C.brd]
2020-12-23 Revert "Revert "minor changes""
    This reverts commit ba90e9202e971c0db24de2081c5a6a48891d21ff.
    [M-Enc-C.brd]
2020-12-23 added M-TrackPad board and schematic
    [M-TrackPad.brd, M-TrackPad.sch]
2021-06-13 minor change
    changed debug baud rate to keep equal specs across devices (M-Brain and
    all M-Controllers print at 115200 baudrate when in debug mode)
2021-06-13 minor changes
    corrected some comment mistakes
    [MButton.ino, MFader.ino, MKnob.ino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]
2021-06-13 added M-Joystick
    The potentiometers on this Sparkfun joystick aren't as good as the
    Bourns potentiometers on M-Knob, giving some 'false' readings. An
    exponential smoothing algorithm was implemented to address this issue.
    [MJoystick.ino]
2021-06-13 MButton debounce
    added debounce to avoid unwanted triggers
    [ButtonDebounce_example.ino, MButton.ino]
2021-06-13 MToggle debounce
    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
    [MToggle.ino]
2021-06-13 added some EEPROM utilities
    easy sketches for reading the entire EEPROM and resetting it to default
    M-Brain values
    [EEPROM_Dump.ino, EEPROM_Preset_Clear.ino]
2021-06-13 added definitions
    used to simplify the preset reset procedure
    [GLOBALS.h]
2021-06-13 removed debug function + some cleanup
    - removed debug function: we can debug using MIDI, there's no actual
    need for (another) serial debug
    - minor fixes but there are still some bugs when mapping controllers
    [GLOBALS.h]
2021-06-14 mapping is working but....
    when mapping another controller, LEDS show the last triggered controller
    mapping instead of blinking to indicate it's ready to map....this was
    not intended and I'm not really sure right now why this is happening but
    it can actually be useful....
    If we press LOAD/CANCEL before mapping the LEDS blink as intended !
2021-06-14 added sketch to test M-Encoder hardware
2021-06-14 starting M-Encoder-C atmel studio project
2021-06-15 implemented encoder+button modes stored to EEPROM
2021-06-15 implemented mode1 and mode2
    mode1 and mode2 have different encoder increments if the encoder button
    is pressed while turning the encoder
2021-06-15 implemented mode3
    in this mode the encoder button acts as a toggle, toggling (ahah)
    between 0 and 127
2021-06-15 implemented mode4
    In this mode the encoder button presses are treated like a MIDI note and
    are sent to a different addres, so the encoders can still be used to map
    CC events
2021-06-15 upload iqs550_arduino_example starting M-Trackpad
    just uploaded the example provided by Azoteq
    notes:
    - could not upload using Arduino IDE, only Atmel Studio...
    - uploaded the code but couldn't get useful data: an error message was
    constantly printed
    - this is way too complex at 4 AM with too little sleep
    - zZzZzZzZzZzZzZzZzZzZ
2023-02-04 fixed note played
    notes played were only programmed for full velocity
    (guess I wasn't expecting continuous controls like knobs to play notes, but now they can)
2023-02-05 Create MJoystick4D.ino
    moded MJoystick to send 4 different values (x+, x-, y+, y-) instead of just x and y
    this was made specifically for Phobos
    in a normal MIDI context this doesn't make sense (think, for example, of Ableton's XY controllers)
    [MJoystick4D.ino]
